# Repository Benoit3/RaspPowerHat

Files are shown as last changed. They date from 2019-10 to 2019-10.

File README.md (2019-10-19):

# RaspPowerHat
A raspberry hat designed to manage raspberry powering from a car battery.<br>
The purpose of the hat is to switch on the RaspBerry when car accessory power is switched on (easy ;-) ) and to switch it off properly (after linux shutdown ) when the car accessory power is switched off (more difficult).

If the PI is not halted 10 minutes after accessory power switch off, the power supply of the PI is cut to avoid to dry the battery.

To achieve this objective, the raspberry itself is powered by a permanent +12V power line through a 5V step down converter. A connection to ACC power supply (switched ignition) allow to switch on and later off the raspberry.<br>

The Hat PCB is designed to fit well on a Raspberry PI Z but can also be used on Raspberry 2 or 3.<br/>
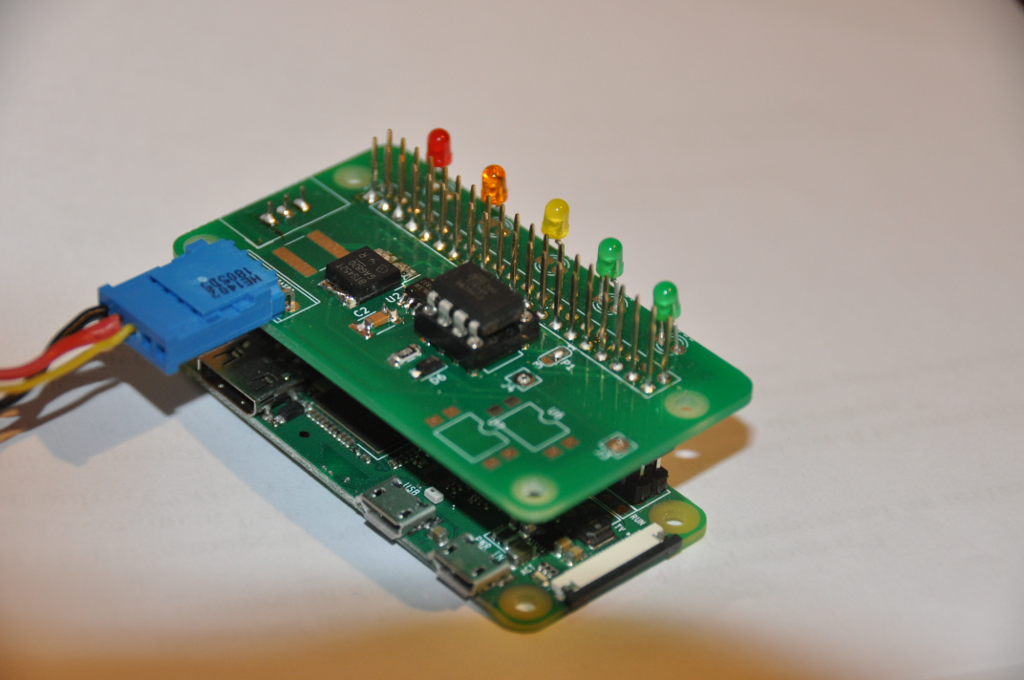
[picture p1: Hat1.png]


Black wire is for ground, red for permanent 12 to 24 V, yellow is for accessories ON or ignition On information

One limitation is the output current of the 5V converter which is 2A. This is the biggest converter I found which can be soldered on the back of the PCB.
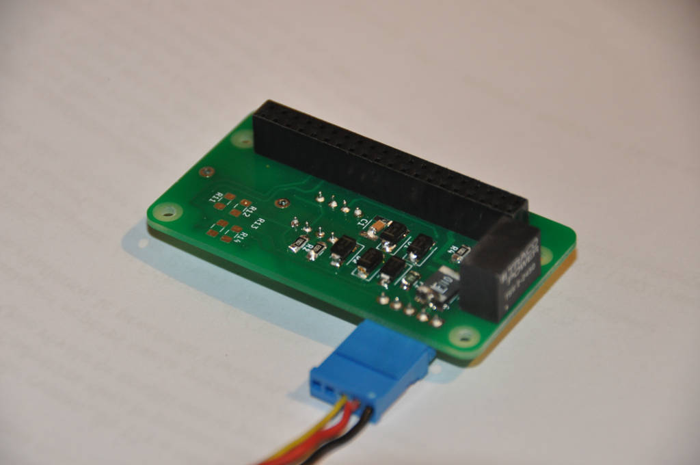
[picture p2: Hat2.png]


The Hat is build using an ATTINY 45.

You can get information about [Hardware and PCB](PCB/README.md), [Firmware](Firmware/README.md) and [PI test software](Software/README.md)

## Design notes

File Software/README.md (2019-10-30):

This folder contains the software script to be run in the Raspberry. It has been tested with Raspbian stretch lite on a Raspberry PI Zero Wifi. 
Scripts are written in Python3.

<h2>Test of the PCB</h2>

You need first to install python3 libraries:<br/>
sudo apt-get install python3-rpi.gpio<br/>
sudo apt-get install python3-smbus<br/>

You need also to modify /boot/config.txt :<br/>

#to enable GPIO26 to go low when cpu is in halted state<br/>
dtoverlay=gpio-poweroff,active_low="y" <br/>

#to enable I2C at 10 kHz speed (low speed is needed to be supported by the ATtiny45 in slave mode)<br/>
dtparam=i2c_arm=on<br/>
dtparam=i2c_arm_baudrate=10000<br/>

You need also to add to the /etc/modules file following lines:<br/>

#request i2c module to be loaded in the kernel<br/>
i2c-dev<br/>

You can now test the PCB with the following line:
python3 i2ctest.py

The script will display ten lines per second like: 0 0 0 [1, 16, 191, 0, 127, 0, 1, 0, 0, 1, 209]
where data are :
- counter of i2c read exception :should stay at 0
- counter of i2c slave busy info : can increase slowly
- counter of i2c frame error (first byte not equal to 1, second to 0x10 (version error), or checksum) : should stay at 0
- 11 byte array :
  - 0: 1 (frame is OK)
  - 1: 16 (frame protocol version 0x10)
  - 2: buffer update counter : incremented every 100 ms 
  - 3: high byte of Vacc value (unit: tenth of volt)
  - 4: low byte of Vacc value (unit: tenth of volt)
  - 5: timer used to validate change of Vacc_Status (unit : 100ms)
  - 6: Vacc_Status
  - 7: high byte of shutting down timer (unit: 1s)
  - 8: low byte of shutting down timer (unit : 1s)
  - 9: Power Status : 1=ON, 2=shutdown requested
  - 10: chksum (XOR of above bytes)

Remark : if byte 9 equal 2, shutting down is requested. Power supply will be switch off as soon as GPIO26 becomes low or shutting down timer is expired (to avoid to dry the battery in case of PI software issue), even if Vacc becomes high again. In this case PI will be powered again and retstart immediately after shutdown.

<h2>Setup of the service</h2>
To have a service continously monitoring Vacc and managing shutdown, you need to copy following files :

RaspPower.service into /etc/systemd/system with following access rights:<br/>
-rw-r--r-- 1 root root 278 Jun 25 22:21 /etc/systemd/system/RaspPower.service

ioManager.py, logging.conf, RaspPower.py, stopManager.py into /home/pi/RaspPower with following access rights:<br/>
-rw-r--r-- 1 pi pi    3138 Jun 25 22:32 ioManager.py<br/>
-rw-r--r-- 1 pi pi     440 Jun 25 21:35 logging.conf<br/>
-rw-r--r-- 1 pi pi    1181 Jun 25 22:29 RaspPower.py<br/>
-rw-r--r-- 1 pi pi     234 Jun 25 21:35 stopManager.py<br/>

You may now try the system with the command : python3 RaspPower.py<br>
Standard output shall display lines like:<br/>
Voltage :13.9 Power Status : 1
Voltage :14.7 Power Status : 1
Voltage :13.4 Power Status : 1

Power status (provided by the Hat) value is 1 in normal mode and becomes 2 when shutdown is requested

To install the service:<br/>
sudo systemctl daemon-reload

To enable the service:<br/>
sudo systemctl enable RaspPower.service

To launch it without waiting a reboot:<br/>
sudo systemctl start RaspPower.service

You are now reading to switch on/off your PI by changing the Vacc input voltage (threshold is 11 V +/- 0.5V)

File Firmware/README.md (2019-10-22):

This folder contains the ATtiny 45 firmware used on the RaspPower Hat.

To add the ATTINY 45 to boards available for Arduino Uno, have a look on [damellis github](https://github.com/damellis/attiny).

The ATtiny 45 shall be used with a 8 MHz clock to answer properly as an I2C slave.

The I2C stack is issued from https://github.com/lucullusTheOnly/TinyWire.

To flash the ATtiny 45, the simple thing is to use SparkFun Tiny AVR Programmer : https://www.sparkfun.com/products/11801

To edit source and flash ATtiny 45, open the RaspPower.ino with the arduino WorkBench, do not forget to set it to 8Mhz.

After that you can go the software folder and test your hat with i2ctest.py by reading README.md [here](../Software/README.md)

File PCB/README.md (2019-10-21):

This folder contains definition of the electronic part of the Hat. 

Schematic and PCBs habe made starting with [template from mikelawrence](https://github.com/mikelawrence/RPi_Zero_pHat_Template). 
Files can be edited with [Kicad PCB](http://www.kicad-pcb.org/) , a Cross Platform and Open Source Electronics Design Automation Suite .
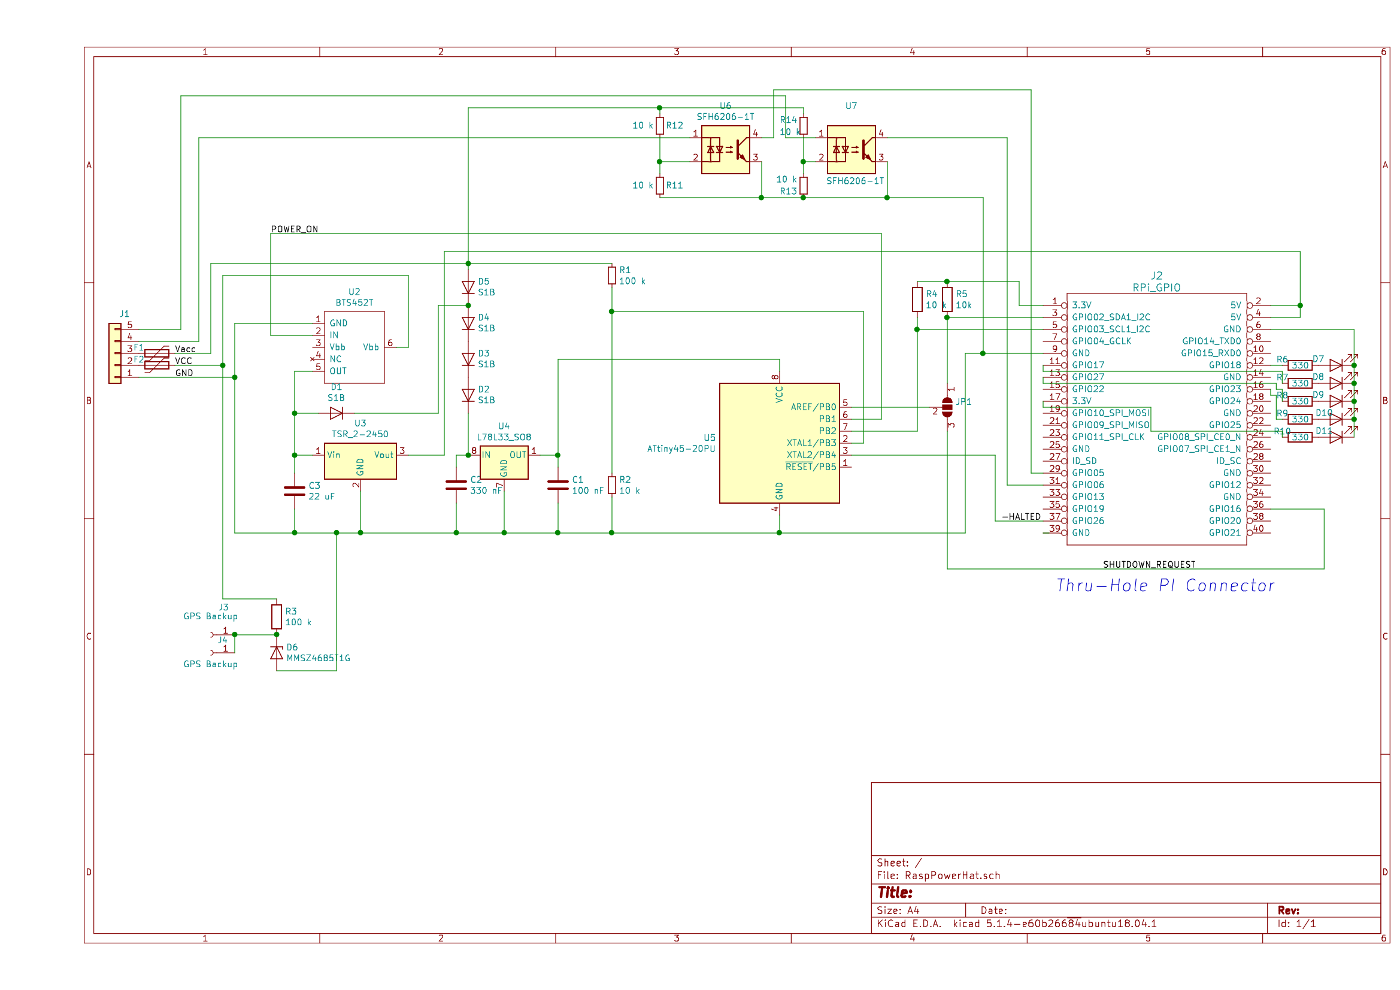
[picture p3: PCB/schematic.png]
Schematic


Some explanation :
- U2 BTS452T is a Smart Power Switch to power the PI through the Traco regulator TSR 2-2450. C3 is not mandatory but recommended by the Traco application note if input voltage of 24V is used. 
- D1 and D5 are to power the 78L33 regulator and then the arduino ATTINY 45 from Vacc or from the U2 power switch.
- In case of usage with a 24V car battery, in charge voltage can grow up to 28 V (normal operation) or even 32 V (overvoltage situation). D2, D3, D4 are there to protect the 78L33 input (maximun rating 30V) in this case.
- R1 are R2 are a divider to provide Vacc voltage information to the ATTINY 45 through  analog input AN3.
- R4, R5 are pull-up for communication I2C bus between the ATTINY 45 and the PI
- JP1 : pin 1 and 2 need to be shorten as the SHUTDOWN request is now done through the I2C bus and not through a dedicated digital input
- J3, J4, R3, D6 are not necessary for a generci usage and were dedicated to data saving of GPS chipset
- R11, R12, R13, R14, U6, U7 are there for additionnal isolated input. But I've never sold neither tested them. Forget them.

References of used components can be browsed by opening schematic file (RaspPowerHat.sch) with KiCad PCB.

File package to order PCB manufacturing can be found [here](PCB.zip)

Here is the result with hand soldering. It is possible to use stackable header to add another PI hat on top of it.
The Hat is larger than a standard PI Zero one to the 5 leds.
- Front side:
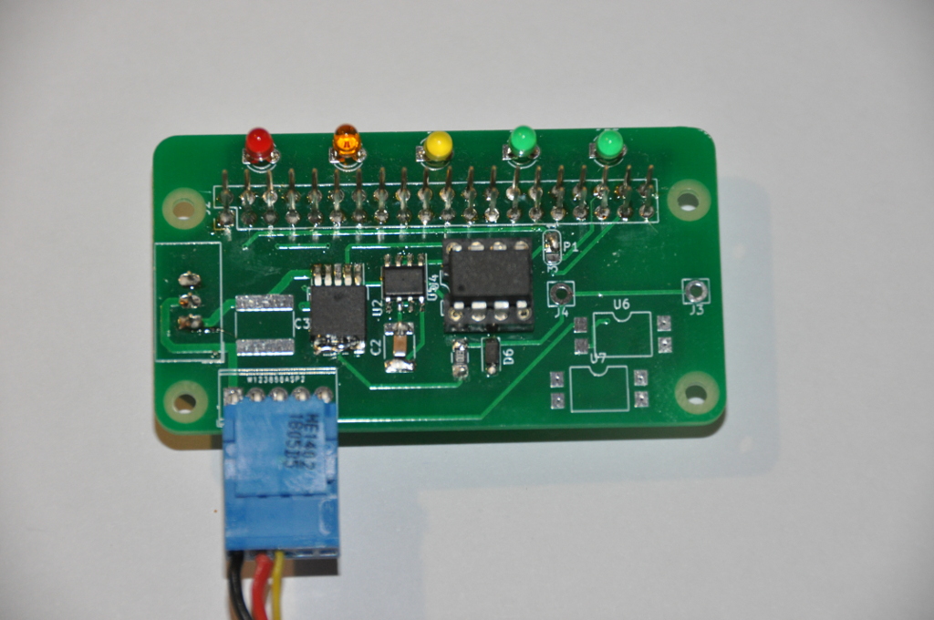
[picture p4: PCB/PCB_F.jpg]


The switched regulator TSR 2-2450 normaly sold on the front side (as on the design) can also be sold on the back side to adjust height of the PCB stack.
- Back side :
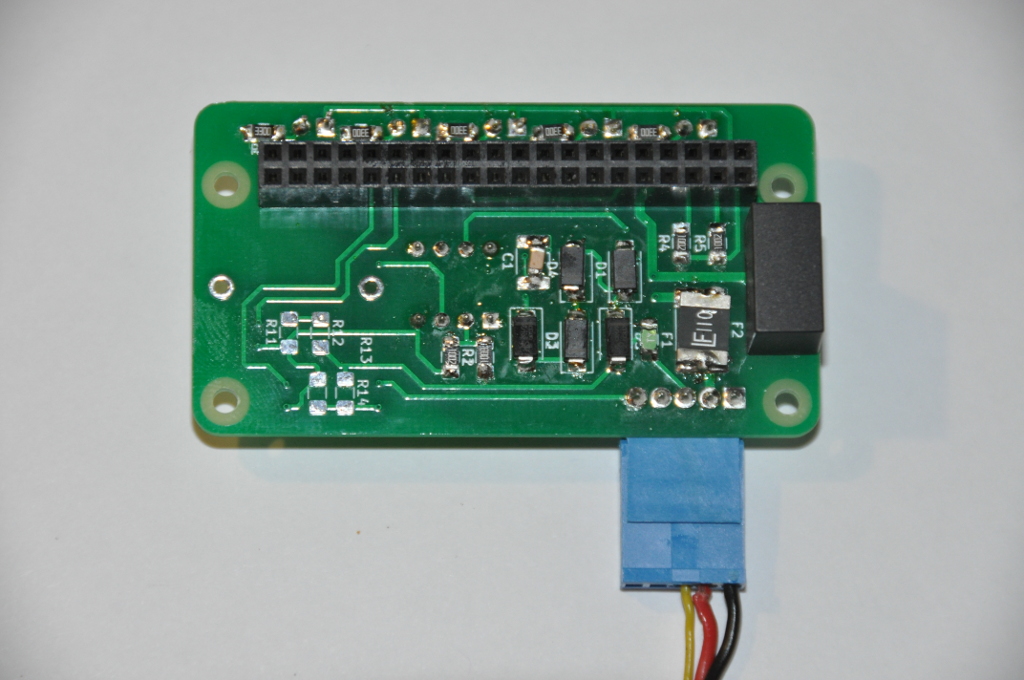
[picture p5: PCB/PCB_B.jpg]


You can now find the ATTINY 45 firmware [here](../Firmware)

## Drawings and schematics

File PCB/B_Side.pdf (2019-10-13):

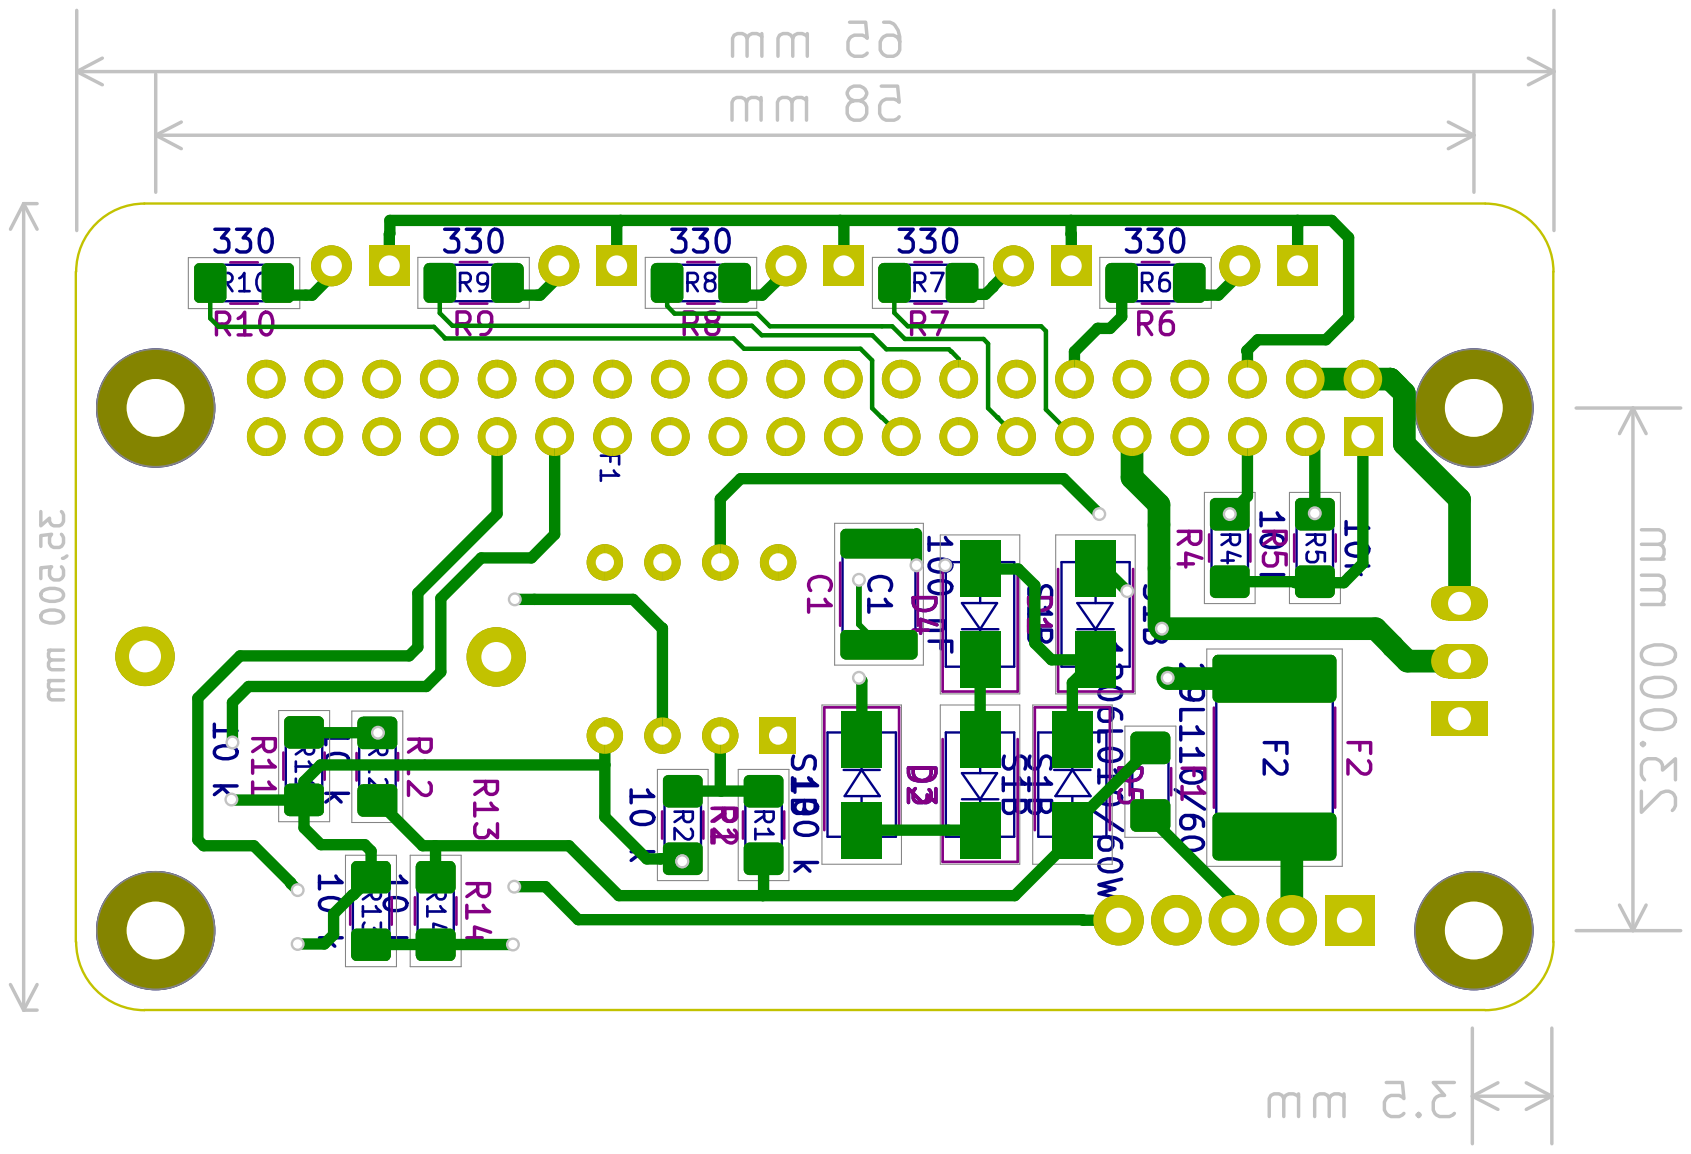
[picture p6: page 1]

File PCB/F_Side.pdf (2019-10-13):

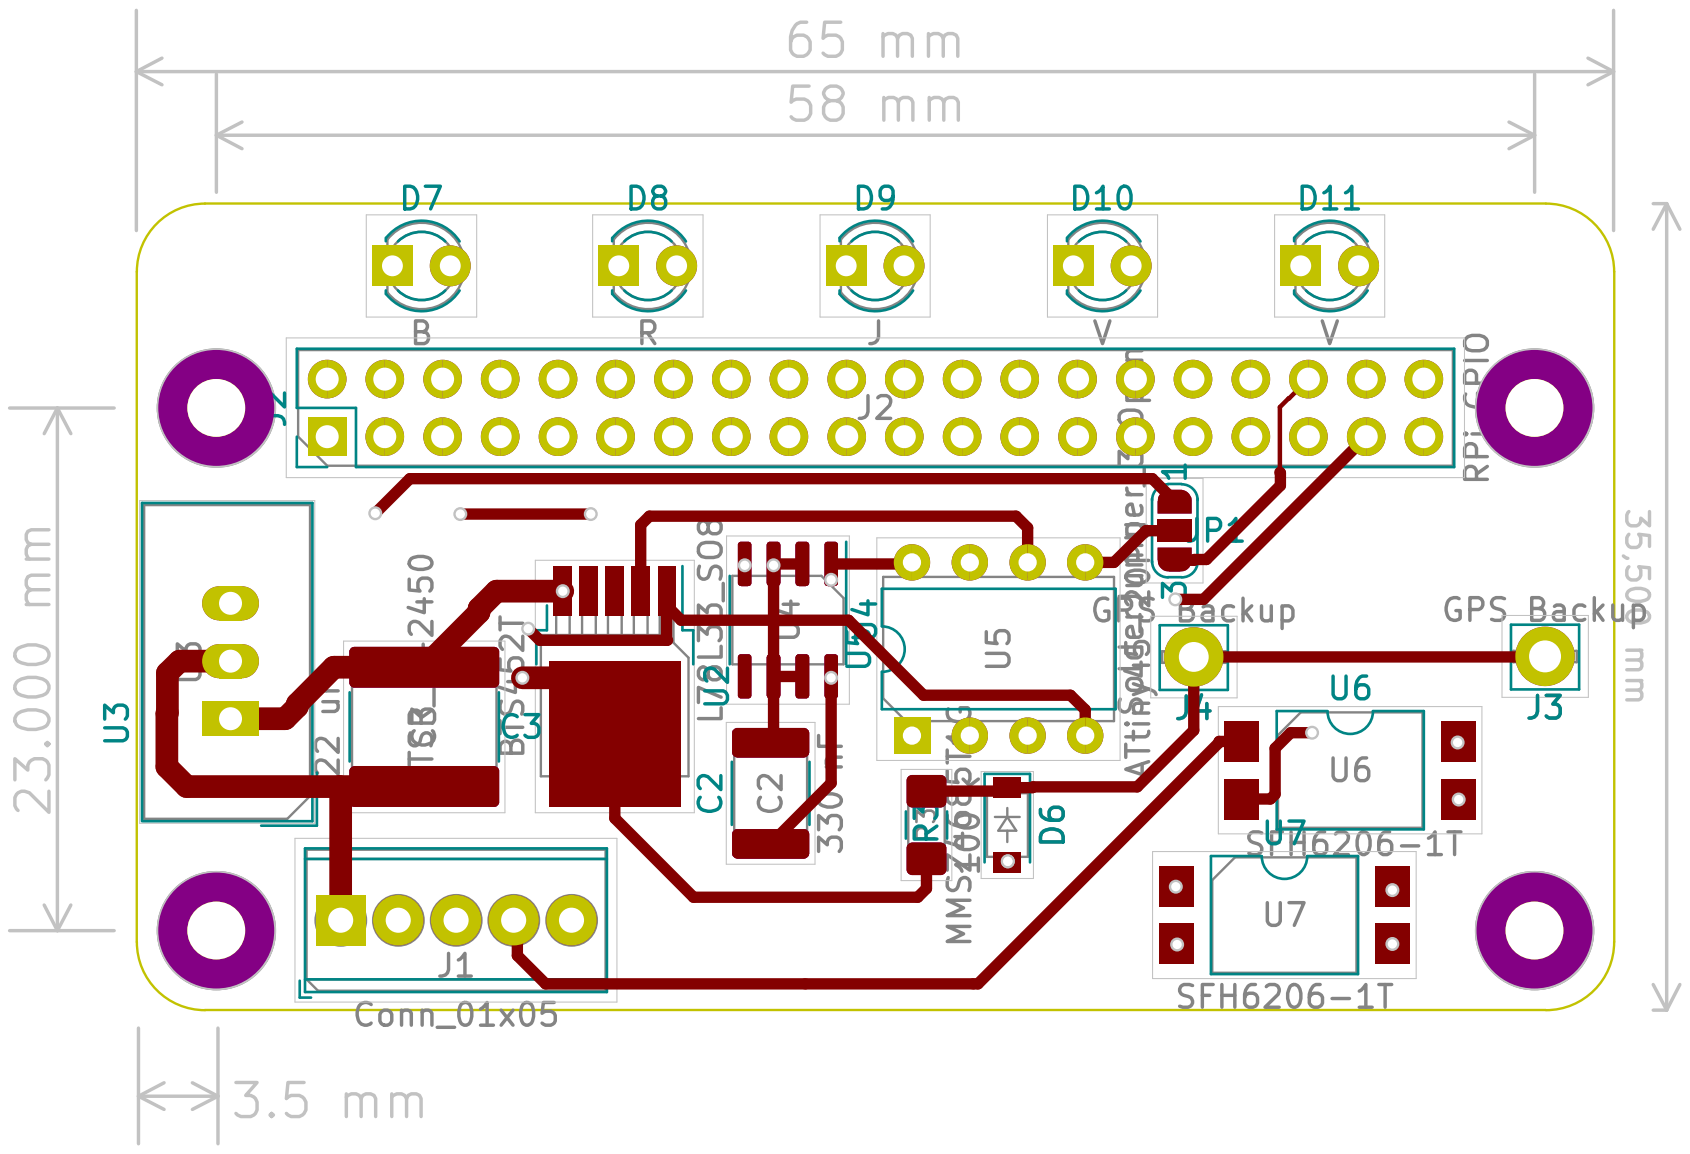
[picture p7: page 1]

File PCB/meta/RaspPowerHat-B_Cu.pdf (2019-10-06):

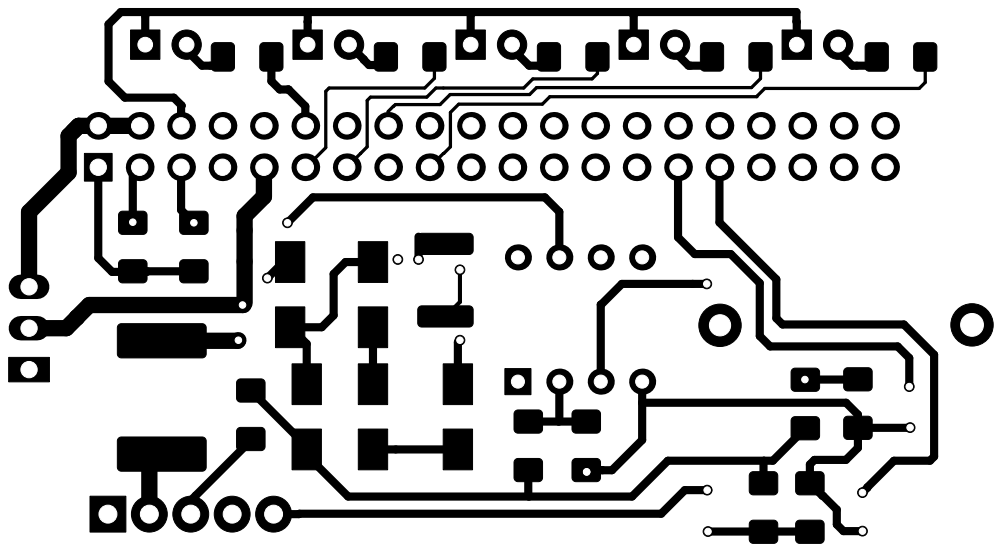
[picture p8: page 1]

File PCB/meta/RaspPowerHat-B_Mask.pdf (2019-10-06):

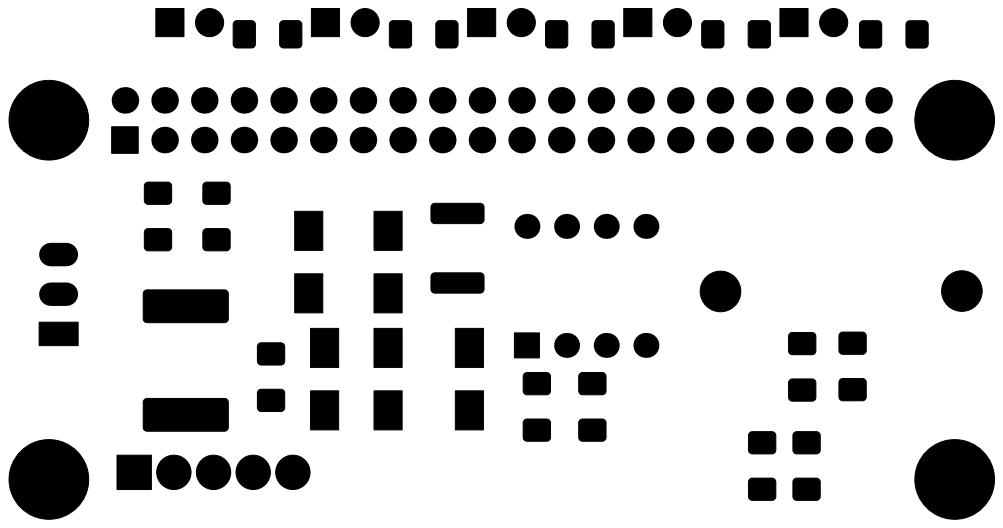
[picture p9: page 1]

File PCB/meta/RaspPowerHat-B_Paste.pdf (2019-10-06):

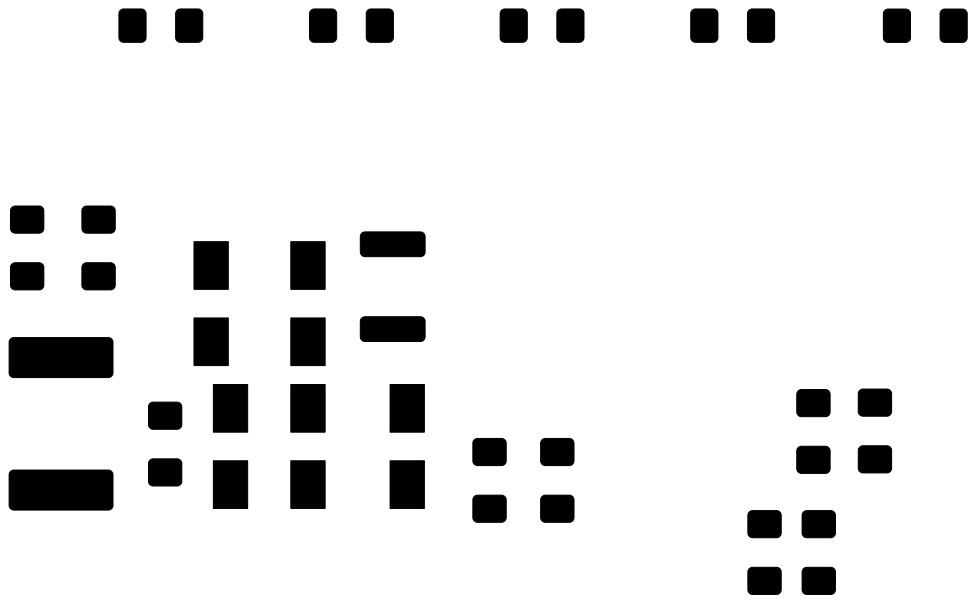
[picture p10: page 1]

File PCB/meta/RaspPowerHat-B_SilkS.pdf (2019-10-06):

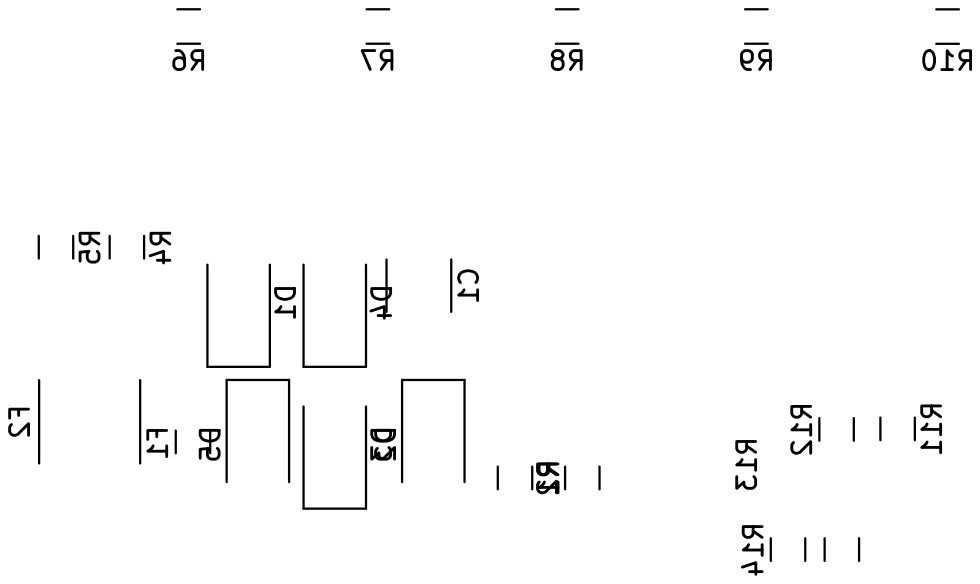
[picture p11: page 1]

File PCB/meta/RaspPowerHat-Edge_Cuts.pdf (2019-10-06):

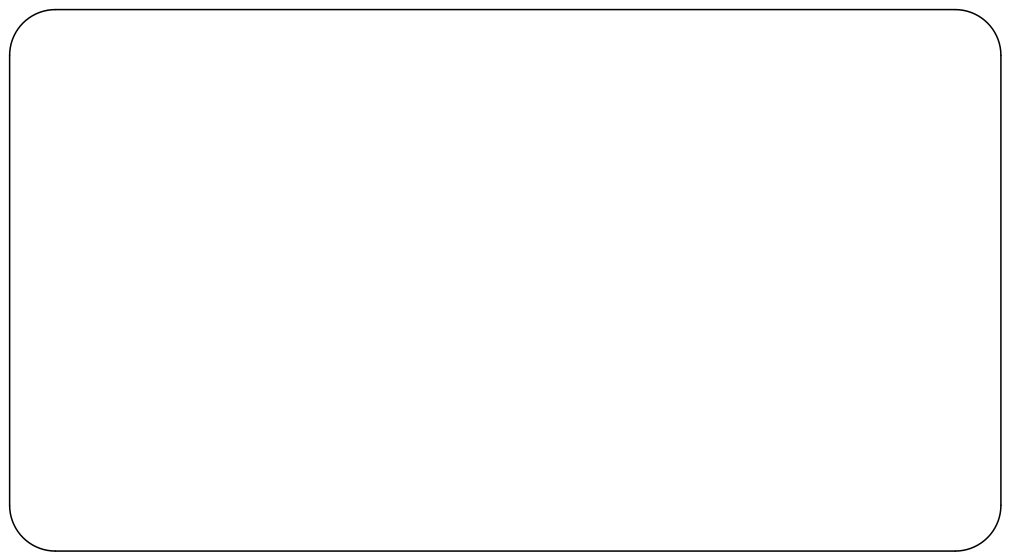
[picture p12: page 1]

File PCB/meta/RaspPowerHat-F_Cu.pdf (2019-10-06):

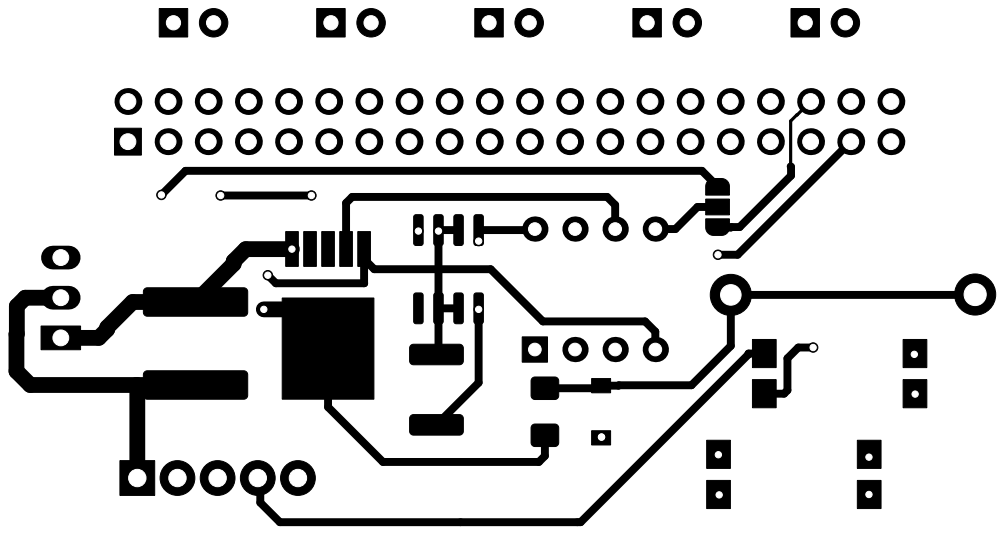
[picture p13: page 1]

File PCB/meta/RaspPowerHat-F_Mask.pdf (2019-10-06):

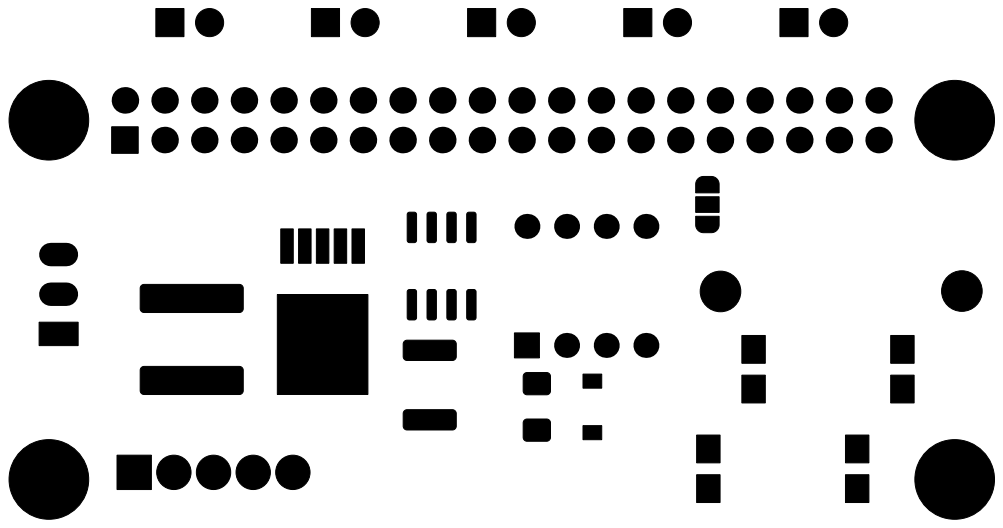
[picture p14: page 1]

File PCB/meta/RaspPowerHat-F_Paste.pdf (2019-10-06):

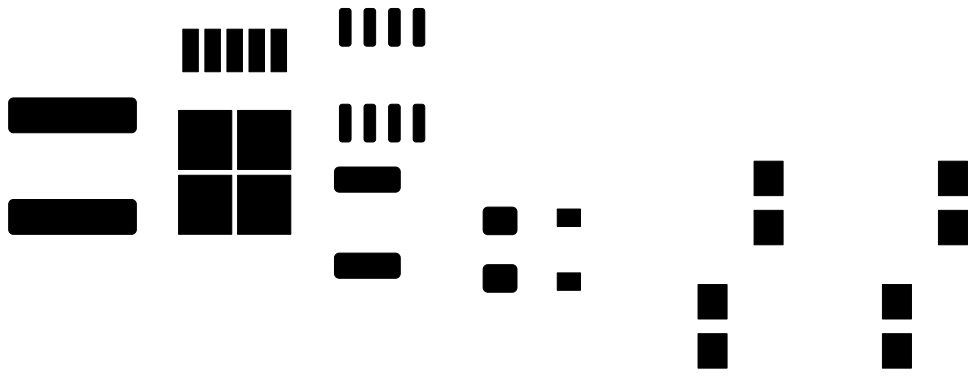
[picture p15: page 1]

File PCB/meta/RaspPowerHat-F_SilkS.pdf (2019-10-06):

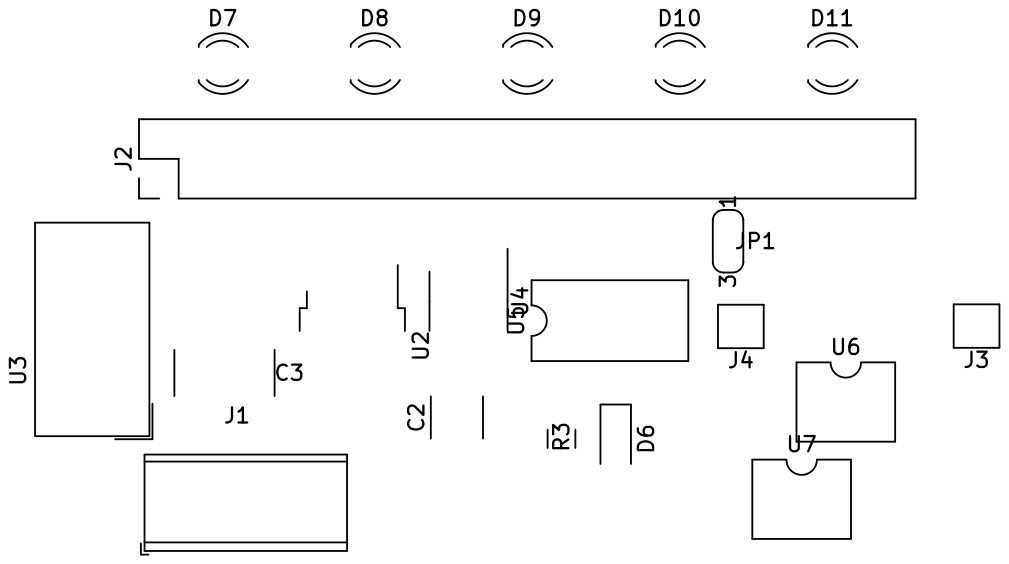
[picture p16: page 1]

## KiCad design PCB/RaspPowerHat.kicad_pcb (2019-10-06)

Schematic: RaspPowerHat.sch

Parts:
C1: 100 nF; C_1812_4532Metric_Pad1.30x3.40mm_HandSolder
C2: 330 nF; C_1812_4532Metric_Pad1.30x3.40mm_HandSolder
C3: 22 uF; C_2225_5664Metric_Pad1.80x6.60mm_HandSolder
D1, D2, D3, D4, D5: S1B; D_SMA
D6: MMSZ4685T1G; D_SOD-123
D7: B; LED_D3.0mm
D8: R; LED_D3.0mm
D9: J; LED_D3.0mm
D10, D11: V; LED_D3.0mm
F1: 1206L010/60WR; Fuse_1206_3216Metric_Pad1.42x1.75mm_HandSolder
F2: 29L110/60; Fuse_2920_7451Metric_Pad2.10x5.45mm_HandSolder
J1: Conn_01x05; TerminalBlock_Phoenix_MPT-0,5-5-2.54_1x05_P2.54mm_Horizontal
J2: RPi_GPIO; Pin_Header_Straight_2x20
J3, J4: GPS Backup; Pin_D1.4mm_L8.5mm_W2.8mm_FlatFork
JP1: SolderJumper_3_Open; SolderJumper-3_P1.3mm_Open_RoundedPad1.0x1.5mm_NumberLabels
R1, R3: 100 k; R_1206_3216Metric_Pad1.42x1.75mm_HandSolder
R2, R4, R11, R12, R13, R14: 10 k; R_1206_3216Metric_Pad1.42x1.75mm_HandSolder
R5: 10k; R_1206_3216Metric_Pad1.42x1.75mm_HandSolder
R6, R7, R8, R9, R10: 330; R_1206_3216Metric_Pad1.42x1.75mm_HandSolder
U2: BTS452T; TO-252-5_TabPin6
U3: TSR_2-2450; Converter_DCDC_TRACO_TSR-2_THT
U4: L78L33_SO8; SOIC-8_3.9x4.9mm_P1.27mm
U5: ATtiny45-20PU; DIP-8_W7.62mm
U6, U7: SFH6206-1T; SMDIP-4_W9.53mm_Clearance8mm

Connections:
/-HALTED: J2.37 (GPIO26), U5.3 (XTAL2/PB4)
/GND: C1.2, C2.2, C3.2, D6.2, J1.1, J2.9 (GND), R2.2, R11.1, R13.1, U2.1 (GND), U3.2 (GND), U4.2, U4.3, U4.6, U4.7, U5.4 (GND), U6.3, U7.3
/POWER_ON: U2.2 (IN), U5.6 (PB1)
/SHUTDOWN_REQUEST: J2.36 (GPIO16), JP1.3
/VCC: F2.1, R3.1, U2.6 (Vbb)
/Vacc: D5.2, F1.1, R1.1, R12.2, R14.1
unnamed: C1.1, U4.1, U5.8 (VCC)
unnamed: C2.1, D2.1, U4.8
unnamed: C3.1, D1.2, U2.5 (OUT), U3.1 (Vin)
unnamed: D1.1, D4.2, D5.1
unnamed: D2.2, D3.1
unnamed: D3.2, D4.1
unnamed: D6.1, J3.1, J4.1, R3.2
unnamed: D7.2, R6.1
unnamed: D8.2, R7.1
unnamed: D9.2, R8.1
unnamed: D7.1, D8.1, D9.1, D10.1, D11.1, J2.6 (GND)
unnamed: D10.2, R9.1
unnamed: D11.2, R10.1
unnamed: F1.2, J1.3
unnamed: F2.2, J1.2
unnamed: J1.4, U6.1
unnamed: J1.5, U7.1
unnamed: J2.1 (3.3V), R4.1, R5.1
unnamed: J2.2 (5V), J2.4 (5V), U3.3 (Vout)
unnamed: J2.3 (GPIO02_SDA1_I2C), JP1.1, R5.2
unnamed: J2.5 (GPIO03_SCL1_I2C), R4.2, U5.7 (PB2)
unnamed: J2.11 (GPIO17), R7.2
unnamed: J2.12 (GPIO18), R6.2
unnamed: J2.13 (GPIO27), R8.2
unnamed: J2.16 (GPIO23), R9.2
unnamed: J2.17 (3.3V), R10.2
unnamed: J2.29 (GPIO05), U6.4
unnamed: J2.31 (GPIO06), U7.4
unnamed: JP1.2, U5.5 (AREF/PB0)
unnamed: R1.2, R2.1, U5.2 (XTAL1/PB3)
unnamed: R11.2, R12.1, U6.2
unnamed: R13.2, R14.2, U7.2

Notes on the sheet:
Thru-Hole PI Connector

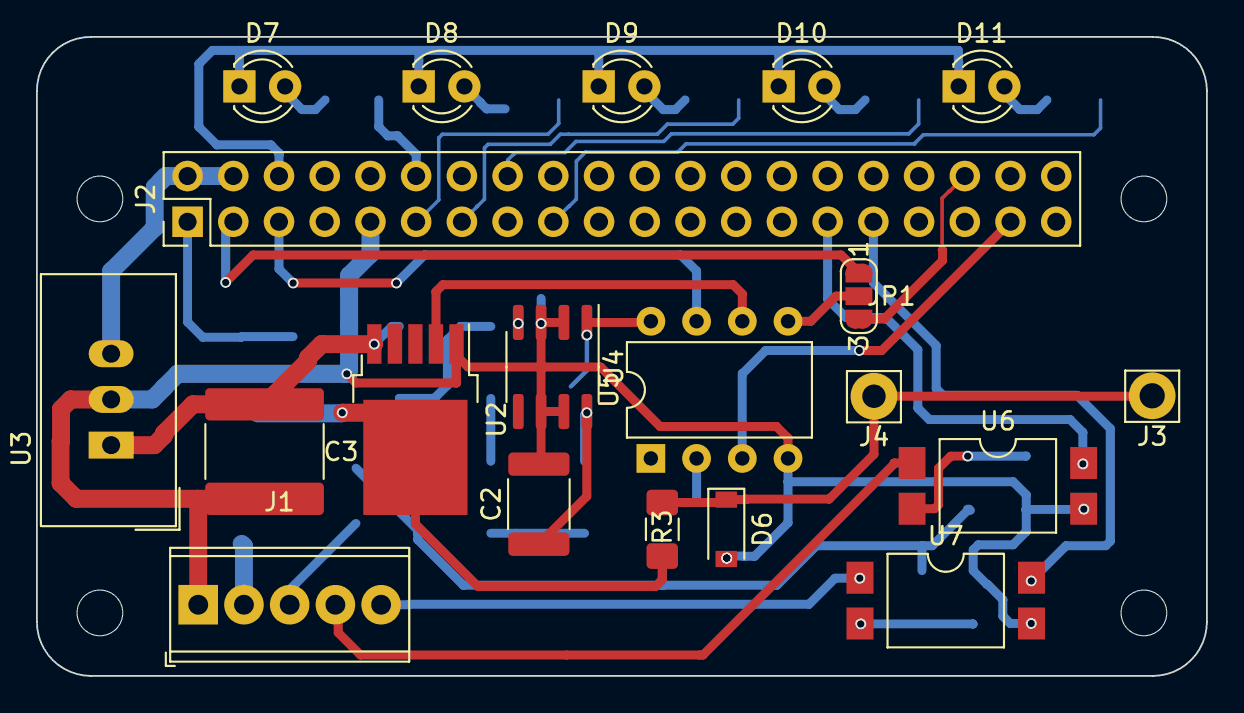
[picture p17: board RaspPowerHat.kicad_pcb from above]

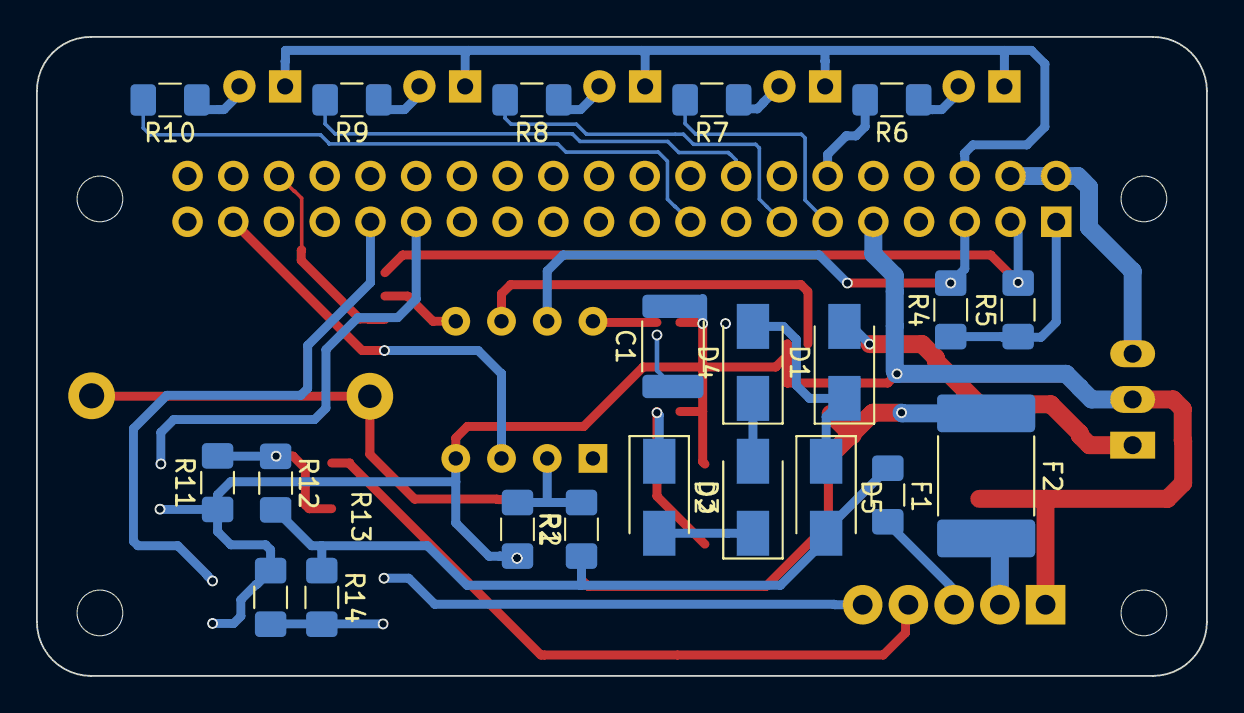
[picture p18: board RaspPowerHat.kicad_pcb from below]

Board: 2 copper layers, 65.0 x 35.5 mm, 41 parts (21 on the bottom side), 38 nets.

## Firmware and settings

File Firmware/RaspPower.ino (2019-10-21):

//This sketch shall be use with a 8MHz clock to allow correct processing of I2C slave mode feature
//The clock of I2C master shall be set to 10 kHz (same reason as above)
#include "TinyWire.h"      // ATTiny wire lib https://github.com/Benoit3/TinyWire

  
//I2C BUS slave address
#define I2C_SLAVE_ADDR 0x27 

//variable used to save I2C slave command
byte mode=0;

//variable used to forbid send of I2C status frame during update of it
volatile bool lock=false;

//Length of stus frame
#define STATUS_FRAME_LENGTH 11

//version of status frame definition
#define STATUS_FRAME_VERSION 0x10

//buffer of the status frame
byte statusFrame[STATUS_FRAME_LENGTH];
//the frame counter is the third ( index=2) of the frame
#define STATUS_FRAME_CNT 2


//VACC measurement
#define VACC_INPUT A3

//Coefficient of ADC to get input voltage (Vref is Vcc)
#define ADC_FACTOR 3.3/1023

//Coefficient of input resistor divider
#define VACC_COEFF 110.0/10.0

//Vacc limit in Volt to detect VAcc is OK
#define VACC_LIMIT 11.0

//Hysteris Threshold in Volt
#define VACC_THRESHOLD 0.5

//Validation time in second to validate Vacc ON state
#define VACC_ON_VAL_TIME 1

//Validation time in second to validate OFF state
#define VACC_OFF_VAL_TIME 5

byte V_Acc_Timeout=0; //V_Acc up timer
unsigned int V_Acc_Int=0;  //Vacc value in tenth of volt;

//PI Interface
#define PI_POWER PB1
#define PI_HALTED PB4

//Pi_Status values
#define PI_OFF 0
#define PI_ON 1
#define PI_SHUTTING_DOWN 2
unsigned char Pi_Status=PI_OFF;

//PI shutting down timeout (in case the PI doesn't go in Halt mode, after the timeout, power is nevertheless switched off)
#define SHUTTING_DOWN_TIMEOUT 600  //10 minutes
unsigned int Shutting_Down_Timer=0;


//V_Acc Status
bool V_Acc_Status=false;

//task scheduling marker
//constant use to manage time variable overflow 32768u
#define TIMEOVERFLOW_THR 32767
unsigned int top100ms;
unsigned int top1s;
unsigned int time;
 
void setup() {
  
  //Set up pin mode to control raspberry power
  digitalWrite(PI_POWER,LOW);
  pinMode(PI_POWER, OUTPUT);

  //Set Up for Raspberry I2C interface
  TinyWire.begin(I2C_SLAVE_ADDR);
  
  //handler function to process received data (after a Stop or Restart)
  //trigered by a stop or restart after having received data
  //TinyWire.onReceive( onI2CReceive ); 
  TinyWire.onRequest( onI2CSend ); 
  
  //Setup pin mode to get raspberry halted status
  pinMode(PI_HALTED,INPUT);
    
  //ADC inititialisation
  pinMode(VACC_INPUT, INPUT);

  //init time top references;
   time=(unsigned int) millis();
   top100ms=time+100;
   top1s=time+1000;

   //init status frame counter
   statusFrame[STATUS_FRAME_CNT]=0;
}


//I2C Slave Receive Callback
//to save address of requested data
void onI2CReceive(int howMany){
  // loops, until all received bytes are read
  
 while(TinyWire.available()>0){
    mode=TinyWire.read(); //remark: mode is still never used
  }
}

void onI2CSend(){
  //if the access to the buffer is not locked
  if (!lock) {
    //send the content of the buffer
    TinyWire.send(statusFrame,STATUS_FRAME_LENGTH);
  }
  //else the a one byte=0 answer 
  else TinyWire.send(0x00);
}

void loop() {
 
  float V_Acc;
  byte index;
  
  //get timestamp
  time=(unsigned int) millis();


  //100ms period processing 
  //check time with rollover robust solution
  if ( (time - top100ms) < TIMEOVERFLOW_THR ) {
  
    top100ms+=100;
    
    //***************************************
    //V_Acc measurement and status processing
    //***************************************
    
    V_Acc=analogRead(VACC_INPUT)*ADC_FACTOR*VACC_COEFF; //float value
    V_Acc_Int=(unsigned int)round(V_Acc*10); //int value in tenth of volt

    //If PI is not powered and V_Acc above ON threshold
    if ( !V_Acc_Status && (V_Acc >= VACC_LIMIT + VACC_THRESHOLD)) {
      //switch V_Acc_Status to True after VACC_ON_VAL_TIME
      if (V_Acc_Timeout==0) V_Acc_Timeout=VACC_ON_VAL_TIME*10; else V_Acc_Timeout--;
      if (V_Acc_Timeout== 0 ) V_Acc_Status=true;    
    }
    //If PI is powered and V_Acc below OFF threshold
    else if ( V_Acc_Status && (V_Acc <= VACC_LIMIT - VACC_THRESHOLD)) {
      if (V_Acc_Timeout==0) V_Acc_Timeout=VACC_OFF_VAL_TIME*10; else V_Acc_Timeout--;
      //switch V_Acc_Status to False after VACC_OFF_VAL_TIME
      if (V_Acc_Timeout== 0 ) V_Acc_Status=false;  
    }
    else {
      V_Acc_Timeout=0;
    }

    //lock and update the frame buffer
    lock=true;
    statusFrame[0]=0x01;
    statusFrame[1]=STATUS_FRAME_VERSION;
    statusFrame[STATUS_FRAME_CNT]++;
    statusFrame[3]=highByte(V_Acc_Int);
    statusFrame[4]=lowByte(V_Acc_Int);
    statusFrame[5]=V_Acc_Timeout;
    statusFrame[6]=(byte)V_Acc_Status;
    statusFrame[7]=highByte(Shutting_Down_Timer);
    statusFrame[8]=lowByte(Shutting_Down_Timer);
    statusFrame[9]=(byte) Pi_Status;
    statusFrame[STATUS_FRAME_LENGTH-1]=0;
    
    //chk processing
    for (index=0;index < (STATUS_FRAME_LENGTH-1);index++) statusFrame[STATUS_FRAME_LENGTH-1]^=statusFrame[index];
    //unlock the buffer
    lock=false;
  }
    
  //1s period activities
  //check time with rollover robust solution
  if ((time - top1s) < TIMEOVERFLOW_THR) {
    top1s+=1000;

  //mangement of PI power switch
    switch(Pi_Status) {
      case PI_OFF:
        if (V_Acc_Status) {
          Pi_Status=PI_ON;
          digitalWrite(PI_POWER,HIGH);
        }
      break;

      case PI_ON:
        if (!V_Acc_Status) {
          Pi_Status=PI_SHUTTING_DOWN;
          Shutting_Down_Timer=SHUTTING_DOWN_TIMEOUT;
        }
      break;

      case PI_SHUTTING_DOWN:

        //If timer is reached or HALT detected
        if( (--Shutting_Down_Timer ==0) || (digitalRead(PI_HALTED)==LOW)) {
          Shutting_Down_Timer =0;
          Pi_Status=PI_OFF;
          digitalWrite(PI_POWER,LOW);
        }
      break;
    }
  }
  
  delay(10);
}

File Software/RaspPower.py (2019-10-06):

#!/usr/bin/env python

from threading import Thread
import logging, logging.config,time,subprocess
import stopManager
import ioManager

if __name__ == '__main__':
	# Initialisation Logger
	logging.config.fileConfig('logging.conf');
	logger = logging.getLogger(__name__);
	
	try:

		#stop Manager
		stop=stopManager.stopManager()

		#io Manager
		io=ioManager.IoManager()
		
		ioThread=Thread(target=io.manager)
		ioThread.daemon=True
		ioThread.start()
		ioShutdownRequested=False
		
		#init led display
		io.setLed(1,io.LED_ON)
	
		#run monitoring service
		shutdownRequested=False; #shutDownRequested init
		
		while not stop.stop_now:
			#check power status
			print("Voltage :"+str(io.supplyVoltage)+ " Power Status : "+str(io.powerStatus))

			#if shutdown has been requested by  power supply
			if ( io.powerStatus==2 and not shutdownRequested) :
				io.setLed(1,io.LED_BLINK)
				cmd='sudo shutdown -h 0'
				subprocess.call(cmd, shell=True)
				shutdownRequested=True

			#loop is done with 1s cycle
			time.sleep(1)

		#io thread end
		logger.info('Stop Requested')
		io.cont=False
		ioThread.join()
	
	except Exception:
    		logger.exception("Fatal exception")
